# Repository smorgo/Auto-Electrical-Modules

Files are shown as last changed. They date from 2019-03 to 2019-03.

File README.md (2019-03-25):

# Auto Electrical Modules
3D printable designs for a suite of modular components to create auto-electrical installations.

The printable components in this project are intended to be compatible with the [MTA Modular Fuse Holder System](http://www.mta.it/en/frames-modules). The MTA Modular Fuse Holder System is available in the UK from such vendors as [12VoltPlanet](https://www.12voltplanet.co.uk/mta-modular-fuse-relay-holding-system.html) and [Polevolt](https://www.polevolt.co.uk/acatalog/Modular_Fuse_and_Relay_System.html).

The project originated from a need to include some electronics in an automotive power distribution system that uses the MTA system. The lack of a suitable module in the MTA range led to the design of a 3D printable enclosure that fits into the MTA frames or brackets, alongside the regular fuse and relay modules.

## Printable Components
The project includes OpenSCAD source code to generate the following components:
* A lidded enclosure with a parameterised height
* End brackets with a parameterised number of module ways
* Module locks for the end brackets [see below](#Module-Locks)
* Standoff spacer to raise genuine MTA brackets (not needed with brackets generated from this project)
* An enclosure insert to hold a PCB and micro-relay. This is specific to my application, but may provide a useful starting point for your own design.

You can use modules generated from this project with its accompanying end brackets, or you can use them with the original MTA backets and frames. Conversely, you can use MTA modules with the brackets generated from this project.

## Rendered Examples
The Renders folder in the repository contain a small number of STL files generated from the OpenSCAD source code, including:
* [40mm tall enclosure module](https://github.com/smorgo/Auto-Electrical-Modules/blob/master/Renders/Module_40mm.stl)
* [Lid for the enclosure module](https://github.com/smorgo/Auto-Electrical-Modules/blob/master/Renders/Module_Lid.stl)
* [Two-way end bracket](https://github.com/smorgo/Auto-Electrical-Modules/blob/master/Renders/mounttest.stl)
* [Locking clip for the end bracket (two needed per bracket)](https://github.com/smorgo/Auto-Electrical-Modules/blob/master/Renders/lock.stl)
* [10mm spacer to raise an MTA 2-way bracket](https://github.com/smorgo/Auto-Electrical-Modules/blob/master/Renders/standoff.stl)
* [Insert for a bespoke PCB and relay](https://github.com/smorgo/Auto-Electrical-Modules/blob/master/Renders/PCB%20Insert.stl)

## Intended Use
I designed this project to complement the MTA Modular Fuse and Relay Holder System, not to replicate it and certainly not to infringe any copyright. Use the project responsibly.

## Module Locks
The standard MTA frames and brackets include a plastic locking tab to hold the modules securely in place. The same design can't be readily replicated in this 3D printed design for two reasons: (1) the tab would normally be printed in mid-air and I'm trying to avoid using supports and (2) the layer structure would be perpendicular to the plane of flex, making it weak and liable to break.

I had a rethink and generated a separate locking component that clips to the end bracket. Being printed separately, it can have the layers oriented parallel to the plane of flex, making it much stronger. It can also be printed completely without the need for supports.

It's not an entirely reliable locking system, yet. Under significant pressure, the lock can disengage. A few more iterations of the design may be useful, but it's reasonably effective and could be made more robust with a well-placed dab of glue.

## Enclosure Lid Fixings
The enclosure and lid are designed to use M2 countersunk
machine screws for fixing and M2 heat inserts in the body
of the enclosure, inserted with a hot soldering iron.
If you want to do something different, you may need to
change some of the screw-related settings.

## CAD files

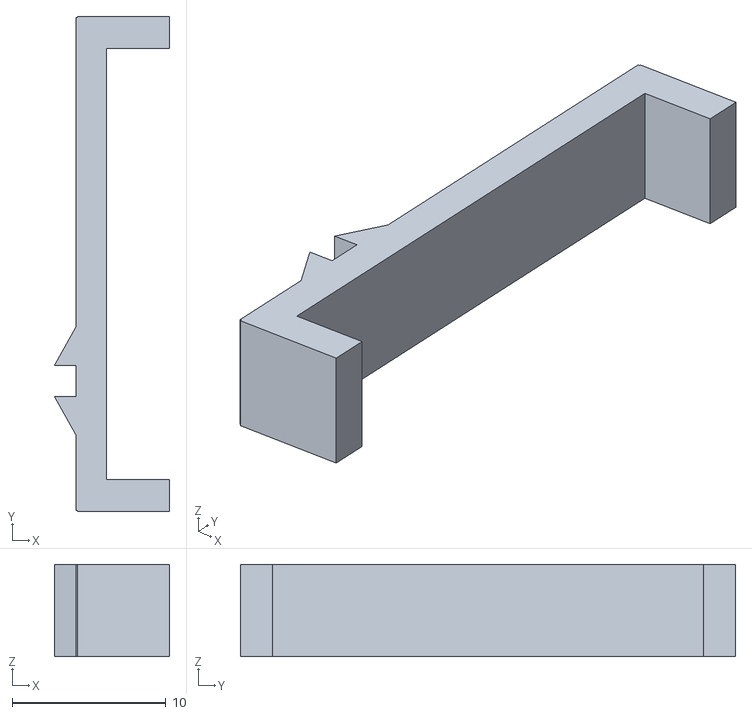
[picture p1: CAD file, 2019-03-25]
Renders/lock.stl
7.50 x 32.2 x 6.00

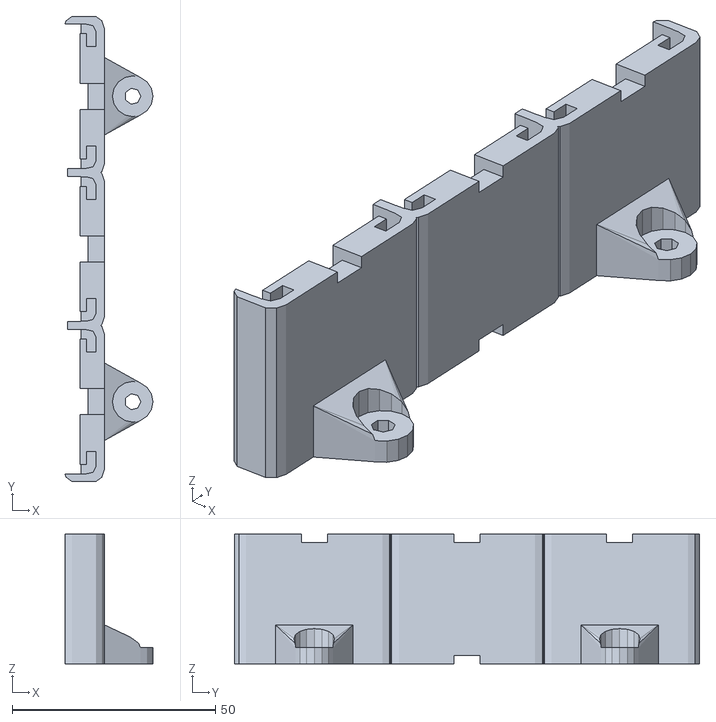
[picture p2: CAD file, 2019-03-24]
Renders/3WayBracket.stl
21.7 x 114.5 x 32.0

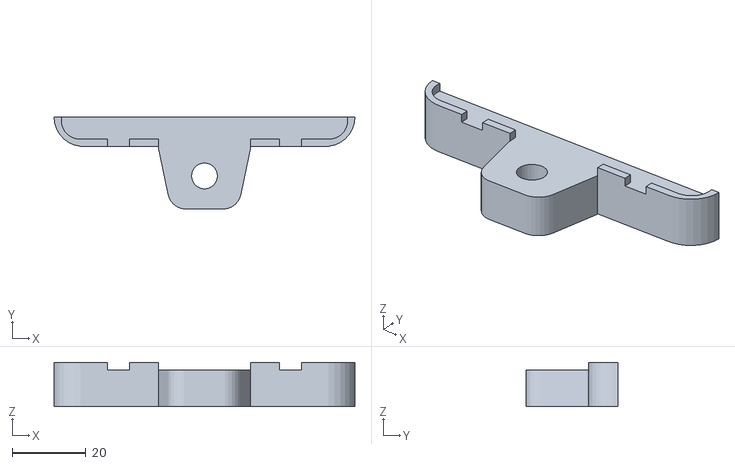
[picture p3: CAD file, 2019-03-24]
Renders/standoff.stl
81.7 x 25.0 x 12.0

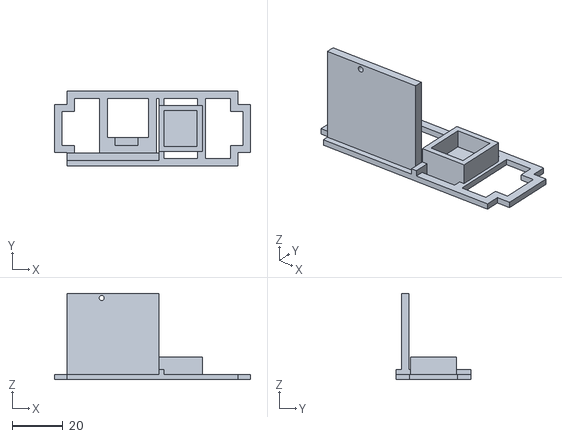
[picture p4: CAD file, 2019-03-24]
Renders/PCB Insert.stl
77.6 x 29.6 x 34.1

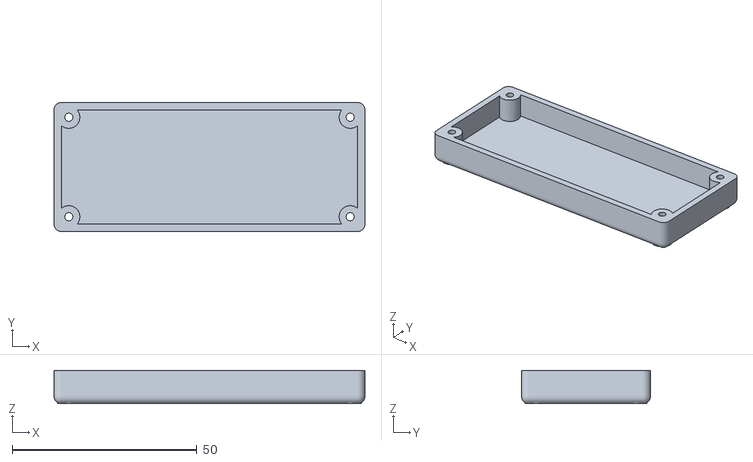
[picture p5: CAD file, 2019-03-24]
Renders/Module_Lid.stl
84.1 x 34.9 x 9.00

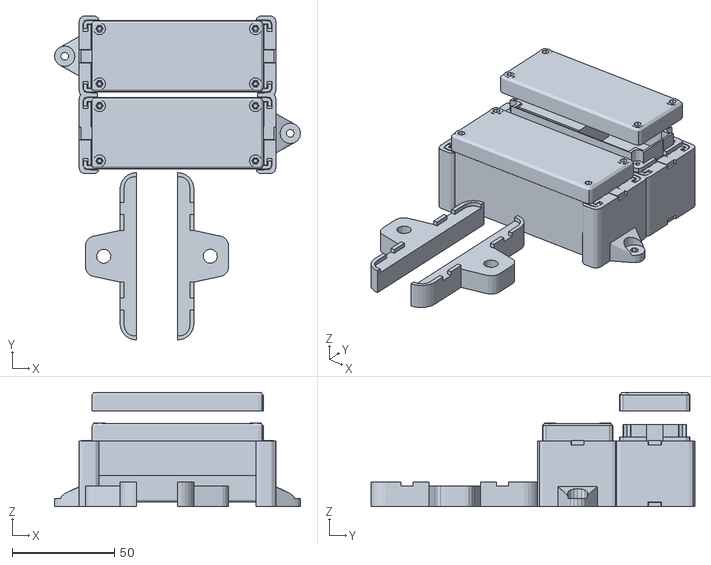
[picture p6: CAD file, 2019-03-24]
Renders/demo.stl
120.1 x 158.1 x 55.8

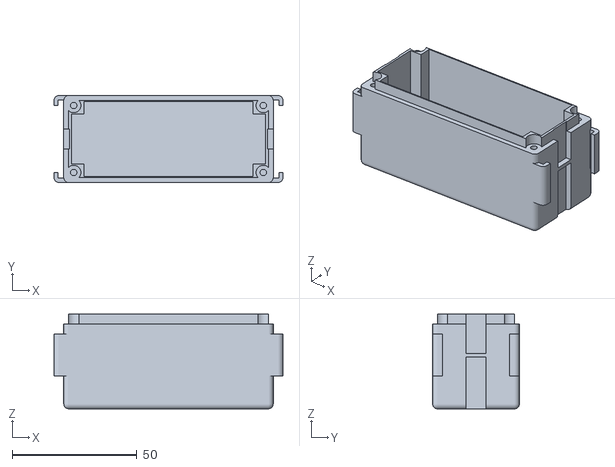
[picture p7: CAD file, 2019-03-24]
Renders/Module_With_Holes.stl
91.9 x 34.9 x 38.0

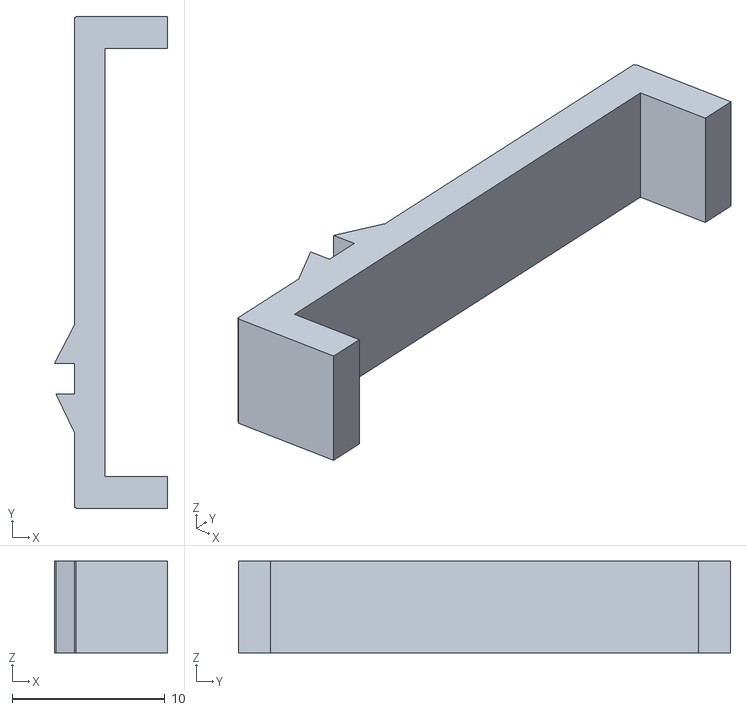
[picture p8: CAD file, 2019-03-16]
Renders/locktest.stl
7.40 x 32.2 x 6.00

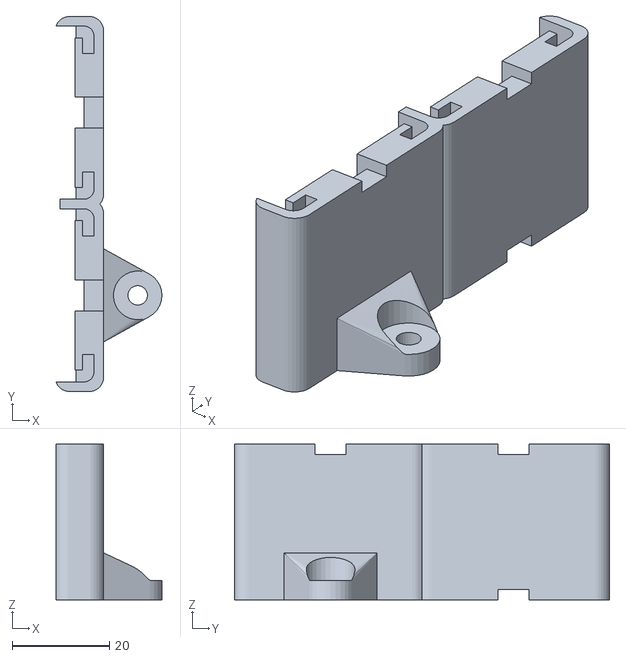
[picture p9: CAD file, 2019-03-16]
Renders/mounttest.stl
21.8 x 77.2 x 32.0

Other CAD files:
Renders/Module_40mm.stl
FuseModuleEnclosure.scad

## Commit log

2019-03-16 Improvements to parameter handling and README.
    [FuseModuleEnclosure.scad, Module_40mm.stl, Module_Lid.stl]
2019-03-24 Added standoffs and PCB insert
    [FuseModuleEnclosure.scad, Module_Lid.stl, Module_With_Holes.stl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]
2019-03-24 Update license and added 3-way bracket
    [3WayBracket.stl]
2019-03-24 Customizer-compatible parameters
    [FuseModuleEnclosure.scad]
2019-03-25 Tweak lock
    [FuseModuleEnclosure.scad, lock.stl]
